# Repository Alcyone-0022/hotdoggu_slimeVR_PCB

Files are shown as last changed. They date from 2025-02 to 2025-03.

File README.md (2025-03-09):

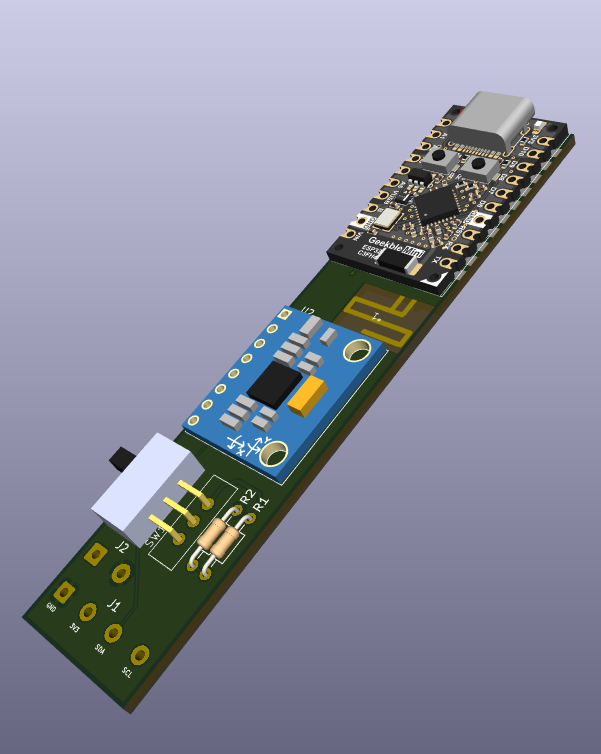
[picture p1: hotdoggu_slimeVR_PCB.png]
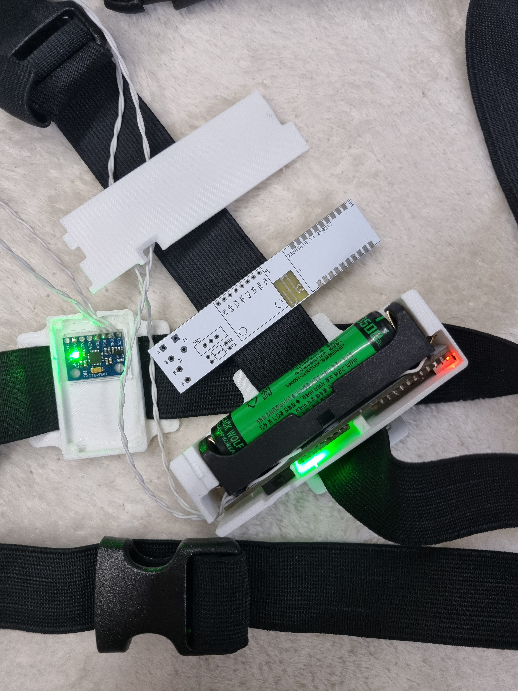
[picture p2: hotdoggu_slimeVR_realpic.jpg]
 
# hotdoggu_slimeVR_PCB
KiCad project - slimevr tracker using Geekble mini ESP32C3, MPU6050    
Includes PCB Antenna (Meandered PIFA 2.4Ghz)    
&nbsp;&nbsp;&nbsp;&nbsp;&nbsp;***Solder 1st pin(left side pin of ant. from top view) to Geekble mini's Ant feed(right side pad from top view)***    
Includes 3d-printable case **(for 18650 cell and socket, needs glue like hot melt for assembly)**
# Used Components
|Component|Description|Link|
|---|---|----|
|Geekble Mini ESP32C3|ESP32C3 module|https://www.devicemart.co.kr/goods/view?no=15483281|
|GY-521|MPU6050 module|https://www.devicemart.co.kr/goods/view?no=1247052|
|MSL-1C2P|Power Switch|https://www.devicemart.co.kr/goods/view?no=38883|
|100k axial resistor|2ea. For battery voltage measurement|-|
|18650 Li-ion cell|1ea. use any 18650 cell or Li-ion battery. Solder to J2. Note: the 3d model in STL files is made for 18650 cell. **This PCB does NOT has charging circuit!**|-|
|BB521|18650 battery socket|https://www.devicemart.co.kr/goods/view?no=12766763|
|26AWG Cable|Connect main to aux IMU. Use or make twisted pair of VCC-SDA/GND-SCK. <a href="https://docs.slimevr.dev/diy/tracker-schematics.html">See slimeVR Documentation</a>|-|
# slimeVR Configuration
**platformio.ini**
```ini
[env:esp32c3]
platform = espressif32 @ 6.7.0
platform_packages =
 framework-arduinoespressif32 @ https://github.com/espressif/arduino-esp32.git#3.0.1
 framework-arduinoespressif32-libs @ https://github.com/espressif/arduino-esp32/releases/download/3.0.1/esp32-arduino-libs-3.0.1.zip
build_flags =
 ${env.build_flags}
 -DESP32C3
board = lolin_c3_mini
```
    
**defines.h**
```C
#define IMU IMU_MPU6050
#define SECOND_IMU IMU_MPU6050
#define BOARD BOARD_CUSTOM
#define IMU_ROTATION DEG_270
#define SECOND_IMU_ROTATION DEG_180
#define PRIMARY_IMU_OPTIONAL false
#define SECONDARY_IMU_OPTIONAL true
#define MAX_IMU_COUNT 2
#ifndef IMU_DESC_LIST
#define IMU_DESC_LIST \
    IMU_DESC_ENTRY(IMU,        PRIMARY_IMU_ADDRESS_ONE,   IMU_ROTATION,        PIN_IMU_SCL, PIN_IMU_SDA, PRIMARY_IMU_OPTIONAL, PIN_IMU_INT) \
    IMU_DESC_ENTRY(SECOND_IMU, SECONDARY_IMU_ADDRESS_TWO, SECOND_IMU_ROTATION, PIN_IMU_SCL, PIN_IMU_SDA, SECONDARY_IMU_OPTIONAL, PIN_IMU_INT_2)
#endif
#define BATTERY_MONITOR BAT_EXTERNAL
#elif BOARD == BOARD_CUSTOM
#define LED_PIN 10
#define LED_INVERTED false
#define PIN_IMU_SDA 3
#define PIN_IMU_SCL 4
#define PIN_IMU_INT 255
#define PIN_IMU_INT_2 255
#define PIN_BATTERY_LEVEL 0
#define BATTERY_SHIELD_RESISTANCE 0
#define BATTERY_SHIELD_R1 100
#define BATTERY_SHIELD_R2 100
```

# Thanks to
SooDragon - the maker of Geekble Mini   
https://github.com/SooDragon/GeekbleMini-ESP32C3.git    
usini - usini_kicad_sensors    
https://github.com/usini/usini_kicad_sensors

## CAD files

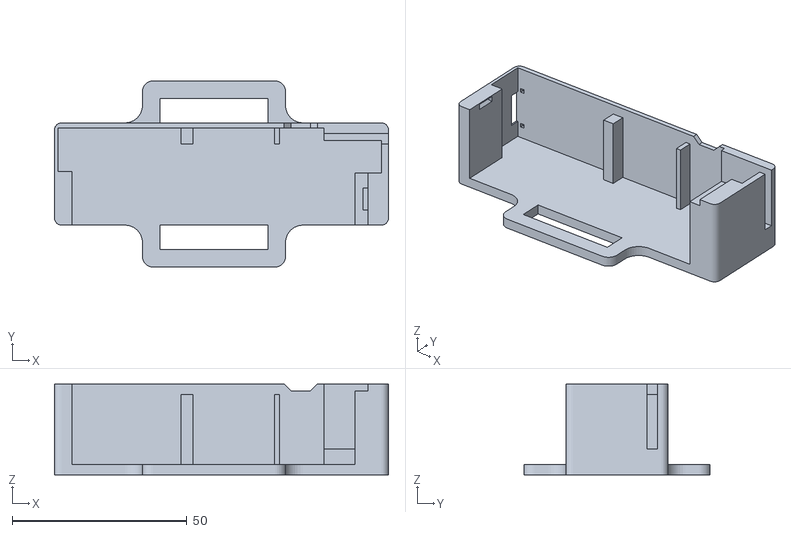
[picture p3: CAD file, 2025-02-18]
STL files/main_housing.stl
95.7 x 53.3 x 26.0

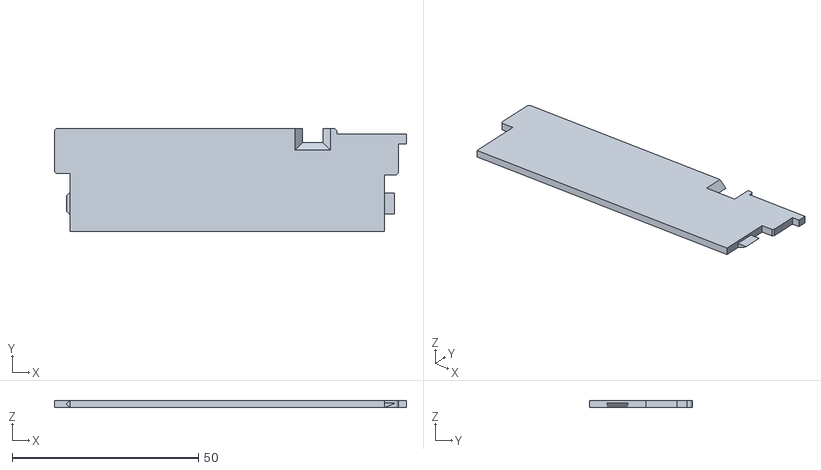
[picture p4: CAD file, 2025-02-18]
STL files/main_housing_lid.stl
94.5 x 27.6 x 2.00

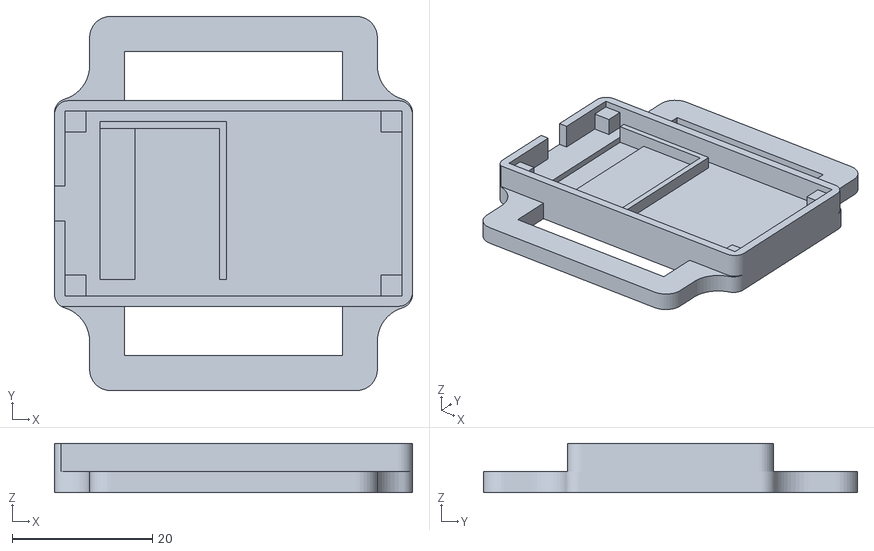
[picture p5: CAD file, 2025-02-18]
STL files/aux_housing.stl
51.0 x 53.3 x 7.00

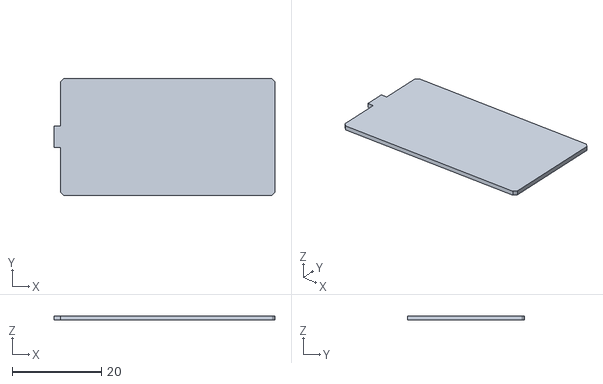
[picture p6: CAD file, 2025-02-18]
STL files/aux_lid.stl
49.4 x 26.2 x 1

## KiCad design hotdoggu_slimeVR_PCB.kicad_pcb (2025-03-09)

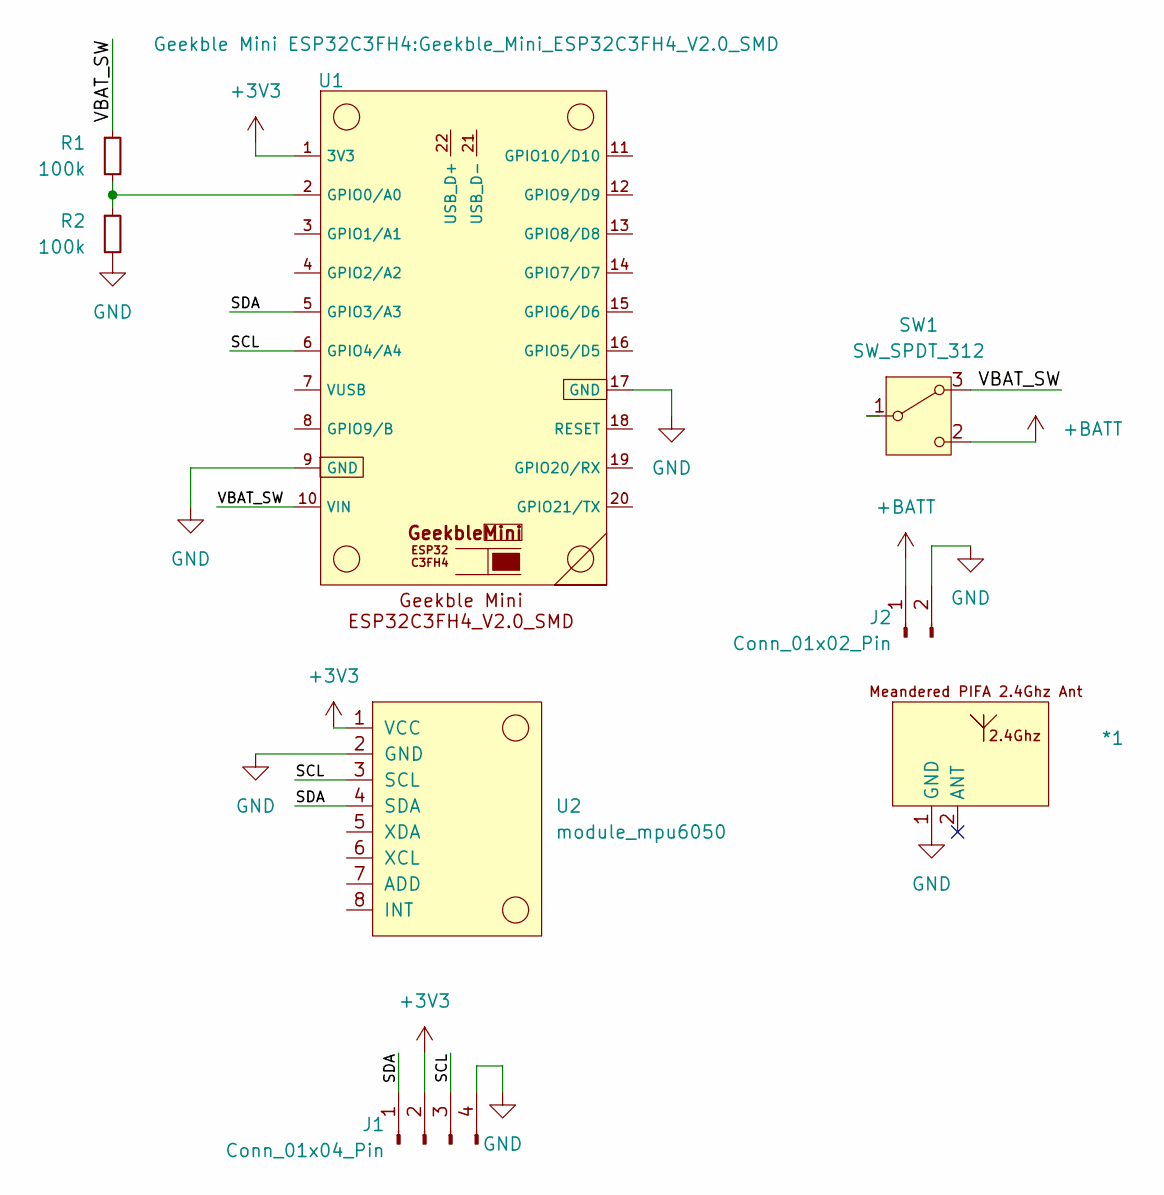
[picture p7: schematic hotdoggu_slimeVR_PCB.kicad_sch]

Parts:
*1: Meandered PIFA 2.4Ghz Ant
J1: Conn_01x04_Pin; SolderWire-0.5sqmm_1x04_P4.6mm_D0.9mm_OD2.1mm
J2: Conn_01x02_Pin; SolderWire-0.5sqmm_1x02_P4.8mm_D0.9mm_OD2.3mm
R1, R2: 100k; R_Axial_DIN0204_L3.6mm_D1.6mm_P7.62mm_Horizontal
SW1: SW_SPDT_312; MSL_1C2P
U1: Geekble_Mini_ESP32C3FH4_V2.0_SMD
U2: module_mpu6050

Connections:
+3V3: J1.2, U1.1 (3V3), U2.1 (VCC)
+BATT: J2.1, SW1.2 (C)
/SCL: J1.3, U1.6 (GPIO4/A4), U2.3 (SCL)
/SDA: J1.1, U1.5 (GPIO3/A3), U2.4 (SDA)
/VBAT_SW: R1.1, SW1.3 (A), U1.10 (VIN)
GND: *1.1 (GND), J1.4, J2.2, R2.2, U1.9 (GND), U1.17 (GND), U2.2 (GND)
unnamed: R1.2, R2.1, U1.2 (GPIO0/A0)

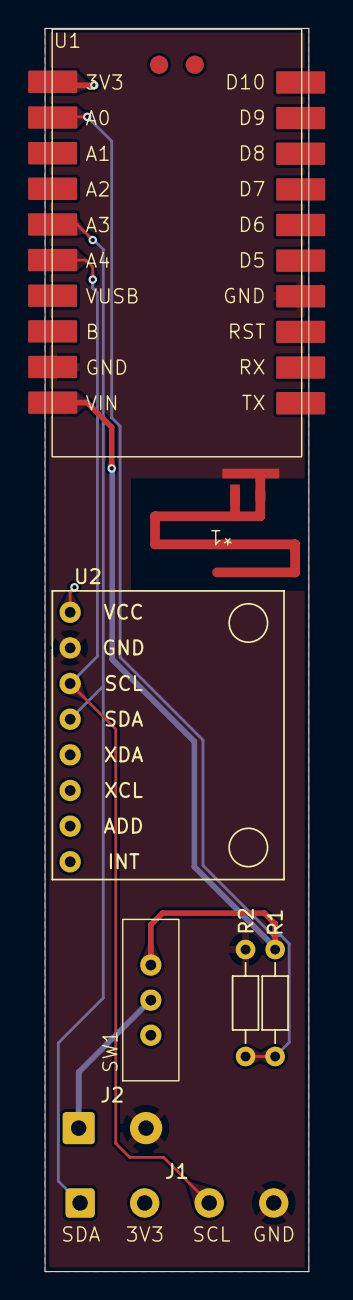
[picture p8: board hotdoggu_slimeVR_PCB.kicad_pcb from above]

Board: 2 copper layers, 18.8 x 88.6 mm, 8 parts (0 on the bottom side), 7 nets.

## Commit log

2025-02-18 initial commit, PCB Rev v2
    [hotdoggu_slimeVR_PCB-B_Cu.gbr, hotdoggu_slimeVR_PCB-B_Mask.gbr, hotdoggu_slimeVR_PCB-B_Paste.gbr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]
2025-02-18 add housing STL files
    [aux_housing.stl, aux_lid.stl, main_housing.stl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]
2025-02-18 some line changes
    [hotdoggu_slimeVR_PCB.kicad_pcb]
2025-02-27 pattern, sym, footprint update
    [hotdoggu_slimeVR_PCB.kicad_pcb, hotdoggu_slimeVR_PCB.kicad_sch]
2025-02-28 seperate sym, lib / update routing
    [hotdoggu_slimeVR_PCB.kicad_pcb, hotdoggu_slimeVR_PCB.kicad_sch]
2025-03-09 changes for GeekbleMini V2.0
    [hotdoggu_slimeVR_PCB-B_Cu.gbr, hotdoggu_slimeVR_PCB-B_Mask.gbr, hotdoggu_slimeVR_PCB-B_Paste.gbr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]
